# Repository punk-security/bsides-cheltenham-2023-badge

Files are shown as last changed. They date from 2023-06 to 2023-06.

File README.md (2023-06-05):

# bsides-cheltenham-2023-badge
The Delorean badge for BSIDES Cheltenham 2023!

We raised over £300 for Mind charity selling parts to complete these on the day!!!!

## Bill Of Materials

You can see a parts list on DigiKey [here](https://www.digikey.co.uk/en/mylists/list/DBJ9N5IB9O)

Essentially its:

* ATTINY402 microcontroller - any spec 402 will do
* Button - any surface mount button fitting the footprint will work
* CR2032 battery clip - surface mount not through hole
* Neopixel addressable LED - Definitely get the right version of these
* Any 3528 Blue LED will work for the bumper rail

## Eagle designs and ordering your own badge

We've uploaded the AutoCAD EAGLE schematic, board design and custom footprints so you can make your own variants!  You will probably have to do some tweaks to get it working as they're designed to be standalone exports.

We've also uploaded the gerber_files.zip.  Take this to JLCPCB and you can order your own exact copies of the board :)

## Writing and flashing code!

We use [MegaTinyCore](https://github.com/SpenceKonde/megaTinyCore) for the arduino interface for ATTINY4x2 chips.

Dev and flashing is done within the Arduino IDE ( < v2 ) using a jtag2updi interface, as discussed [here](https://github.com/SpenceKonde/AVR-Guidance/blob/master/UPDI/jtag2updi.md)

We use [these little usb sticks](https://amzn.eu/d/c0lx0wG), with a 4.7k resistor soldered between the Tx and Rx lines.  

### Installing MegaTinyCore dependencies

This board package can be installed via the board manager in arduino. The boards manager URL is:

`http://drazzy.com/package_drazzy.com_index.json`

1. File -> Preferences, enter the above URL in "Additional Boards Manager URLs"
2. Tools -> Boards -> Boards Manager...
3. Wait while the list loads (takes longer than one would expect, and refreshes several times).
4. Select "megaTinyCore by Spence Konde" and click "Install". For best results, choose the most recent version.

### Setting up the IDE

1. Open the file **bsides-cheltenham-2023-badge.ino** in arduino
2. Select tools > Board > megaTinyCore > ATtiny412/402/212/202
3. Select tools > Chip > ATtiny402
4. Select tools > Clock > 8Mhz internal *(we get power issues otherwise)*
5. Select tools > Programmer > SerialUPDI SLOW
6. Select tools > Port > ( pick your COM port)

### Flashing firmware
1. Connect the 3v3 pin to 3v on your usb (maybe wedge it in the battery clip)
2. Connect GND to GND
3. Connect UPDI to the RxD port
4. Click Upload button

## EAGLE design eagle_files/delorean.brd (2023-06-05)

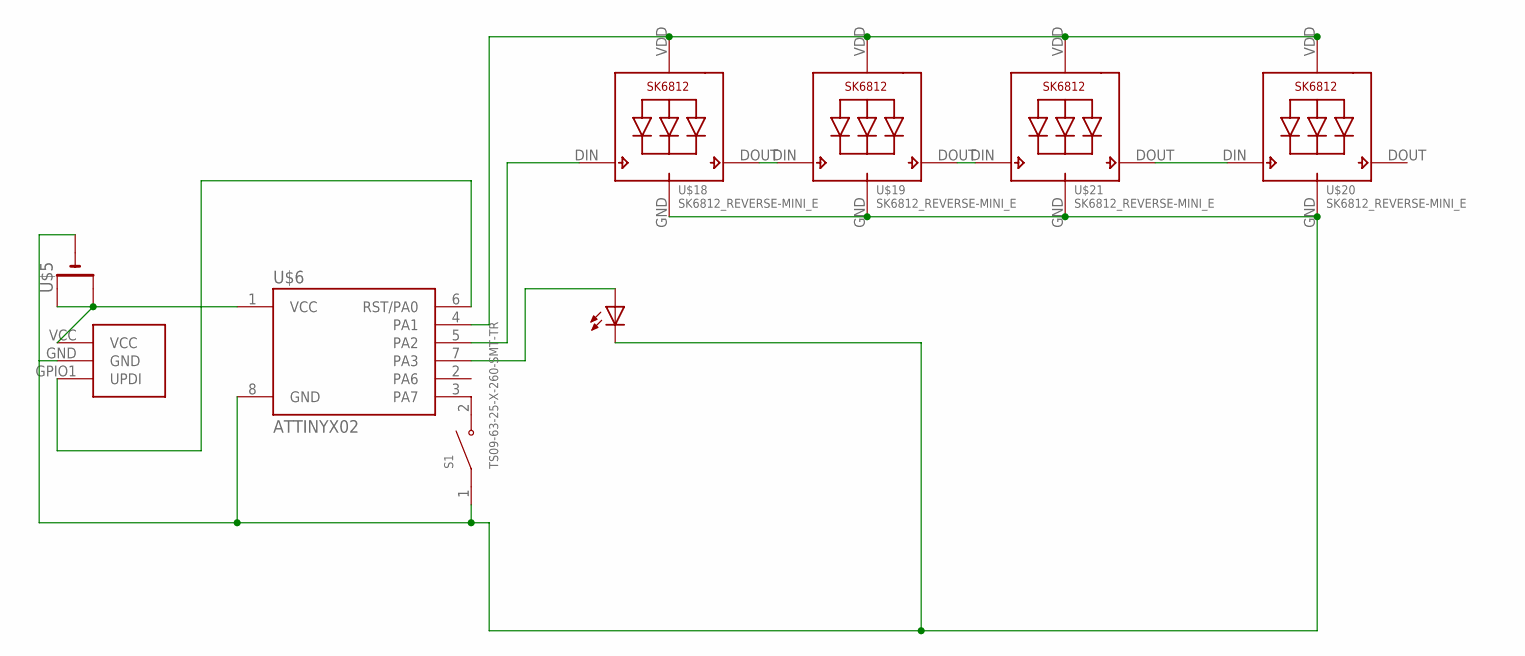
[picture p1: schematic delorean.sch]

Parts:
S1: TS09-63-25-X-260-SMT-TR; SW_TS09-63-25-X-260-SMT-TR
U$1: LED_SMD_REVERSEMOUNT3528; B/3528-21R
U$5: CR2032SMT; CR2032-SMD
U$6: ATTINYX02; SOIC08_JEDEC_150MIL
U$7: SAO; SAO_SMD
U$18, U$19, U$20, U$21: SK6812_REVERSE-MINI_E; SK6812-MINI-E

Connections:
GND: S1.1, U$1.+ (C), U$5.-, U$6.8 (GND), U$7.GND, U$18.GND, U$19.GND, U$20.GND, U$21.GND
LED: U$1.- (A), U$6.7 (PA3)
unnamed: U$6.6 (RST/PA0), U$7.GPIO1 (UPDI)
unnamed: U$5.+$1 (+), U$5.+$2 (+1), U$6.1 (VCC), U$7.VCC
unnamed: S1.2, U$6.3 (PA7)
unnamed: U$18.DOUT (DO), U$19.DIN (DI)
unnamed: U$6.4 (PA1), U$18.VDD, U$19.VDD, U$20.VDD, U$21.VDD
unnamed: U$6.5 (PA2), U$18.DIN (DI)
unnamed: U$19.DOUT (DO), U$21.DIN (DI)
unnamed: U$20.DIN (DI), U$21.DOUT (DO)

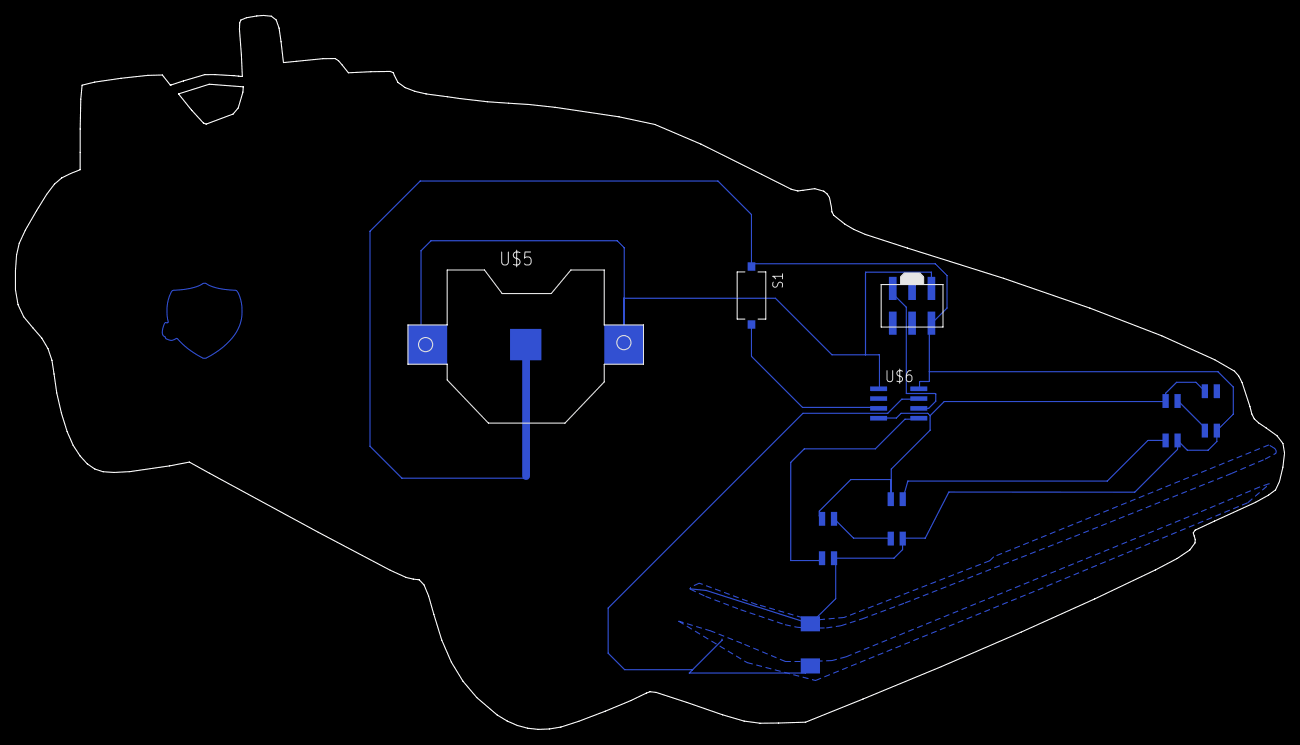
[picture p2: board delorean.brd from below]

Board: 2 copper layers, 164.2 x 92.4 mm, 9 parts (9 on the bottom side), 10 nets.

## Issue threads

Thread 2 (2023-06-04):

Parts List

ptf569, 2023-06-04:
Hey guys, buzzing after the conf and really want to make the badge with by son.

Could you throw up some links for the parts needed please.

Thanks

PTF

SimonGurney, 2023-06-04:
I'll get the list properly updated tomorrow as well as adding the eagle files in case you want to make your own version :)

For now, here is the part list from digikey.

If anyone wants a bag of components then DM me at simon@punksecurity.co.uk and I'll put a bulk order in and get them posted out in a week or two.  Same deal, donate £10 to mind.org.uk and send us proof.

 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

Closed 2023-06-05.

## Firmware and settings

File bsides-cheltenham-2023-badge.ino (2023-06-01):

#include <avr/io.h>-
#include <avr/pgmspace.h>
#include <EEPROM.h>
#include <avr/sleep.h>
#include <tinyNeoPixel_Static.h>

#define BUTTON_PIN PIN_PA7
#define BUMPER_POWER PIN_PA3
#define HEADLIGHT_POWER PIN_PA1
#define HEADLIGHT_GPIO PIN_PA2

#define NUMLEDS 4
#define LEFT 0
#define LEFTMID 1
#define RIGHTMID 2
#define RIGHT 3

#define OFF 0,0,0
#define RED 100,0,0
#define GREEN 0,100,0
#define BLUE 0,0,100
#define ORANGE 100,40,0
#define PINK 60,0,40
#define PURPLE 60,0,80
#define OLIVE 20,20,0
#define YELLOW 60,60,0
#define YELLOWGREEN 100,150,100
#define WHITE 80,80,100

byte pixels[NUMLEDS * 3];
tinyNeoPixel strip = tinyNeoPixel(NUMLEDS, HEADLIGHT_GPIO, NEO_GRB, pixels);

uint8_t state;

uint16_t time_pin_low(uint16_t max_ms)
{
  // blocking for up to max_ms
  if (digitalRead(BUTTON_PIN) == HIGH)
  {
    return(0);
  }
  delay(50); //debounce-
  uint16_t t = 50;
  while(digitalRead(BUTTON_PIN) == LOW)
  {
    delay(5);
    t = t + 5;
    if ( t > max_ms )
      return(max_ms);
  }
  return(t);
}

void setAllPixels(int r, int g, int b, bool show = false)
{
  for (int i = 0; i < NUMLEDS; i++) 
  {
    strip.setPixelColor(i,r,g,b);
  }
  if(show)
    strip.show();
}

void setBumper(int brightness)
{
    if (!(state & B00000001))
      return;
    analogWrite(BUMPER_POWER, brightness);
      return;
}

int police(int x)
{
  if( x % 2 == 0)
  {
    strip.setPixelColor(LEFT,RED);
    strip.setPixelColor(LEFTMID,BLUE);
    strip.setPixelColor(RIGHT,RED);
    strip.setPixelColor(RIGHTMID,BLUE);
  }
  else
  {
    strip.setPixelColor(LEFTMID,RED);
    strip.setPixelColor(LEFT,BLUE);
    strip.setPixelColor(RIGHTMID,RED);
    strip.setPixelColor(RIGHT,BLUE);
  }
  strip.show();
  return 150;
}


int chase(int x, uint8_t r,uint8_t g, uint8_t b)
{
  strip.setPixelColor((x - 1) % 5,OFF); // turn last pixel off
  strip.setPixelColor((x % 5),r,g,b); // set current pixel
  strip.show();
  return 200;
}

int pumpkin(int x)
{
  chase(x+1,2,1,0);
  chase(x,ORANGE);
  chase(x-1,2,1,0);
  return 200;
}

int rainbow(int x)
{
  //red,orange,green.blue.purple
  strip.setPixelColor((x+4) % NUMLEDS,RED);
  strip.setPixelColor((x+3) % NUMLEDS,ORANGE);
  strip.setPixelColor((x+2) % NUMLEDS,GREEN);
  strip.setPixelColor((x+1) % NUMLEDS,BLUE);
  strip.setPixelColor((x) % NUMLEDS,PURPLE);
  strip.show();
  return 300;
}

int xmas(int x)
{
  if(x % 3 == 0)
  {
    strip.setPixelColor(LEFT,RED);
    strip.setPixelColor(LEFTMID,GREEN);
    strip.setPixelColor(RIGHTMID,YELLOW);
    strip.setPixelColor(RIGHT,RED);
  }
  else if(x % 3 == 1)
  {
    strip.setPixelColor(LEFT,YELLOW);
    strip.setPixelColor(LEFTMID,RED);
    strip.setPixelColor(RIGHTMID,RED);
    strip.setPixelColor(RIGHT,GREEN);
  }
  else
  {
    strip.setPixelColor(LEFT,YELLOW);
    strip.setPixelColor(LEFTMID,GREEN);
    strip.setPixelColor(RIGHTMID,GREEN);
    strip.setPixelColor(RIGHT,YELLOW);
  }
  strip.show();
  return 300;
}

int pink(int x)
{
  if(x % 2 == 0)
  {
    strip.setPixelColor(LEFT,PINK);
    strip.setPixelColor(LEFTMID,PURPLE);
    strip.setPixelColor(RIGHTMID,PINK);
    strip.setPixelColor(RIGHT,PURPLE);
  }
  else
  {
    strip.setPixelColor(LEFTMID,PINK);
    strip.setPixelColor(LEFT,PURPLE);
    strip.setPixelColor(RIGHT,PINK);
    strip.setPixelColor(RIGHTMID,PURPLE);
  }
  strip.show();
  return 200;
}



int headlights(int x)
{
  int interval = x % 80;
  if(interval == 0)
  {
    strip.setPixelColor(LEFT,WHITE);
    strip.setPixelColor(LEFTMID,WHITE);
    strip.setPixelColor(RIGHTMID,WHITE);
    strip.setPixelColor(RIGHT,WHITE);
  }
  else if (interval == 2)
  {
    strip.setPixelColor(LEFTMID,OFF);
    strip.setPixelColor(LEFT,OFF);
    strip.setPixelColor(RIGHT,OFF);
    strip.setPixelColor(RIGHTMID,OFF);
  }
  else if (interval == 3)
  {
    strip.setPixelColor(LEFTMID,WHITE);
    strip.setPixelColor(LEFT,WHITE);
    strip.setPixelColor(RIGHT,WHITE);
    strip.setPixelColor(RIGHTMID,WHITE);
  }
  else if (interval == 40)
  {
    setBumper(255);   
  }
    else if (interval == 41)
  {
    setBumper(0);   
  }
    else if (interval == 42)
  {
    setBumper(255);   
  }
      else if (interval == 43)
  {
    setBumper(0);   
  }
    else if (interval == 44)
  {
    setBumper(255);   
  }
  else if (interval == 79)
  {
    strip.setPixelColor(LEFTMID,OFF);
    strip.setPixelColor(LEFT,OFF);
    strip.setPixelColor(RIGHT,OFF);
    strip.setPixelColor(RIGHTMID,OFF);
    setBumper(0); 
  }
  strip.show();
  return 100;
}

void success()
{
  analogWrite(PIN_PA3, 255); // SET EEPROM
  for(int j = 0; j < 4; j++)
  {
    setAllPixels(0,255,0,true);
    delay(50);
    setAllPixels(0,0,0,true);
    delay(50);
  }
  analogWrite(PIN_PA3, 0); // SET EEPROM
  EEPROM.update(0, state);
  delay(200);
}

void fail()
{
  analogWrite(PIN_PA3, 255); // SET EEPROM
  for(int j = 0; j < 4; j++)
  {
    setAllPixels(255,0,0,true);
    delay(50);
    setAllPixels(0,0,0,true);
    delay(50);
  }
  analogWrite(PIN_PA3, 0); // SET EEPROM
  delay(200);
}

int breath(uint8_t min, uint8_t max, int n, int step = 5)
{
  if (!(state & B00000001))
    return;
  int range = (max - min) / step;
  int i = n % (range * 2);
  if (i < range)
  {
    analogWrite(PIN_PA3, min + (i * step));
  }
  else
  {
    analogWrite(PIN_PA3, (max * 2) - (i * step));
  }
  return 100;
}

int flash(int x)
{
    if (!(state & B00000001))
    return;
    if(x % 2 == 0)
  {
    analogWrite(PIN_PA3,255);
  }
  else
  {
    analogWrite(PIN_PA3,0);
  }
}

int knightrider(int i, int r, int g, int b)
{
  int n = i % 7;
  setAllPixels(0,0,0,true);
  if (n > 3)
  {
    n = 3 - (n - 4);
  }
  strip.setPixelColor(n,r,g,b);
  strip.show();
  return 60;
}

int knightrider_game(int i, int target_pixel)
{
  int n = i % 7;
  setAllPixels(0,0,0,true);
  if (n > 3)
  {
    n = 3 - (n - 4);
  }
  strip.setPixelColor(n,255,0,0);
  if (n != target_pixel)
  strip.setPixelColor(target_pixel,0,5,0);
  strip.show();
  return n;
}

int level(int ms_delay, int target_pixel)
{
  int i, current_pixel;
  while(true)
  {
    for(i=0;i<8;i++)
    {
      current_pixel = knightrider_game(i, target_pixel);
      if (press_detected(ms_delay) != ms_delay)
        // a button has been pressed 
        {
          if (current_pixel == target_pixel)
            return 1;
          else
            return 0;
        }
    }
  }
}

uint16_t press_detected(uint16_t max_ms)
{
  // blocking for up to max_ms
  if (digitalRead(BUTTON_PIN) == LOW)
  {
    return(0);
  }
  delay(10); //debounce-
  uint16_t t = 10;
  while(digitalRead(BUTTON_PIN) == HIGH)
  {
    delay(1);
    t = t + 1;
    if ( t > max_ms )
      return(max_ms);
  }
  while(digitalRead(BUTTON_PIN) == LOW)
  {
    delay(1);
    }
  return(t);
}

void playGame(int l)
{
  while(true)
  {
    if(level(l,random(0,3)) == 1)
    {
      l = l - 10;
      setAllPixels(0,255,0,true);
      delay(200);
    }
    else
    {
      // YOU LOSE
      fail();
      return;
    }
    if (l < 41)
    {
      state = state | B00000001;
      success();
      return;
    }
  }
}




void sleep()
{
  // turn off leds
  strip.setPixelColor(LEFT,OFF);
  strip.setPixelColor(LEFTMID,OFF);
  strip.setPixelColor(RIGHTMID,OFF);
  strip.setPixelColor(RIGHT,OFF);
  strip.show();
  set_sleep_mode(SLEEP_MODE_PWR_DOWN);
  PORTA.PIN7CTRL = PORT_PULLUPEN_bm | PORT_ISC_LEVEL_gc; // enable pullup and interrupt
  digitalWrite(HEADLIGHT_POWER, LOW);
  digitalWrite(BUMPER_POWER, LOW);
  sleep_enable();
  sleep_cpu();
  // sleep resumes here
  PORTA.PIN7CTRL = PORT_PULLUPEN_bm; // renable pullup but no interrupt
  digitalWrite(HEADLIGHT_POWER, HIGH);
}

ISR(PORTA_PORT_vect) {
  PORTA.INTFLAGS = PORT_INT7_bm; // Clear Pin 7 interrupt flag otherwise keep coming back here
}


void setup()
{
  // Power save
  // http://www.technoblogy.com/show?2RA3
  // https://github.com/SpenceKonde/megaTinyCore/blob/master/megaavr/extras/PowerSave.md
  ADC0.CTRLA &= ~ADC_ENABLE_bm; // Disable ADC
  pinMode(HEADLIGHT_POWER, OUTPUT);
  pinMode(HEADLIGHT_GPIO, OUTPUT);
  pinMode(BUMPER_POWER, OUTPUT);
  // UPDI does not need setting (PA0)

  // Pin setup
  pinMode(BUTTON_PIN, INPUT_PULLUP);
  digitalWrite(HEADLIGHT_POWER, HIGH);

  
  state = EEPROM.read(0);
  if (state == B11111111)
  {
    EEPROM.update(0, 0);
    state = EEPROM.read(0);
  }
  
}

void loop()
{
  int mode = 0;
  int interval;
  uint16_t button_low_time = 0;
  uint16_t total_interval = 0;
  strip.begin();
  int i = 0;
  while(true)
  {
    if ( mode == 0 )
    {
      interval = headlights(i);
    }
    else if ( mode == 1)
    {
      interval = police(i);
      flash(i);
    }
    else if ( mode == 2)
    {
      interval = pink(i);
      breath(0,250,i);
    }
    else if ( mode == 3)
    {
      interval = xmas(i);
    }
    else if ( mode == 4)
    {
      interval = rainbow(i);
      breath(100,250,i);
    }
        else if ( mode == 5)
    {
      interval = pumpkin(i);
    }
    else if ( mode == 6 )
    {
      interval = knightrider(i,255,0,0);
      breath(100,250,i);
    }
     else if ( mode == 7 )
    {
      interval = knightrider(i,0,255,0);
      breath(100,250,i);
    }
      else if ( mode == 8 )
    {
      interval = knightrider(i,0,0,255);
      breath(100,250,i);
    }
    else
    {
      mode = 0;
      continue;
    }
    i++;
    // This section breaks down the sleep interval to catch button presses
    total_interval = total_interval + interval;
    while(interval > 0)
    {
      delay(10);
      interval = interval - 10;
      button_low_time = time_pin_low(2000);
      if (button_low_time > 0)
      {
       /*
       * MAIN MENU
       * RAPID PRESS = CHANGE MODE
       * SHORT PRESS = ENTER GAME
       * LONG PRESS = TURN OFF
       */
        if (button_low_time > 1800)
        {
        //SLEEP
          setAllPixels(0,0,0,true);
          while(digitalRead(BUTTON_PIN) == LOW)
            delay(10);
          sleep();
        }
        else if (button_low_time > 500)
        {
          playGame(100);
        }
        else
        {
          analogWrite(BUMPER_POWER,0);
          mode = mode +1;
        }
        i = 0;
        total_interval = 0;
        // reset timer
      }
  }
  }
}
